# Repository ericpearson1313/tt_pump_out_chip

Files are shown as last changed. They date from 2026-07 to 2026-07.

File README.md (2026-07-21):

   

# Tiny Tapeout Project: Liquid Pump Controller

- [chip datasheet](docs/LPC_Datasheet.pdf)
- [documentation for Tiny Tapeout chip](docs/info.md)
- [documentation for Tiny Tapeout tests](test/README.md)
- [documentation for MAX10 development fpga](max10/fpga.md)
- [documentation for forge production fpga](max10/fpga.md)
- [documentation for the Dev board PCB](pcb/pcb.md)

## What is Tiny Tapeout?

Tiny Tapeout is an educational project that aims to make it easier and cheaper than ever to get your digital and analog designs manufactured on a real chip.

To learn more and get started, visit https://tinytapeout.com.

## Set up your Verilog project

1. Add your Verilog files to the `src` folder.
2. Edit the [info.yaml](info.yaml) and update information about your project, paying special attention to the `source_files` and `top_module` properties. If you are upgrading an existing Tiny Tapeout project, check out our [online info.yaml migration tool](https://tinytapeout.github.io/tt-yaml-upgrade-tool/).
3. Edit [docs/info.md](docs/info.md) and add a description of your project.
4. Adapt the testbench to your design. See [test/README.md](test/README.md) for more information.

The GitHub action will automatically build the ASIC files using [LibreLane](https://www.zerotoasiccourse.com/terminology/librelane/).

## Enable GitHub actions to build the results page

- [Enabling GitHub Pages](https://tinytapeout.com/faq/#my-github-action-is-failing-on-the-pages-part)

## Resources

- [FAQ](https://tinytapeout.com/faq/)
- [Digital design lessons](https://tinytapeout.com/digital_design/)
- [Learn how semiconductors work](https://tinytapeout.com/siliwiz/)
- [Join the community](https://tinytapeout.com/discord)
- [Build your design locally](https://www.tinytapeout.com/guides/local-hardening/)

## What next?

- [Submit your design to the next shuttle](https://app.tinytapeout.com/).
- Edit [this README](README.md) and explain your design, how it works, and how to test it.
- Share your project on your social network of choice:
  - LinkedIn [#tinytapeout](https://www.linkedin.com/search/results/content/?keywords=%23tinytapeout) [@TinyTapeout](https://www.linkedin.com/company/100708654/)
  - Mastodon [#tinytapeout](https://chaos.social/tags/tinytapeout) [@matthewvenn](https://chaos.social/@matthewvenn)
  - X (formerly Twitter) [#tinytapeout](https://twitter.com/hashtag/tinytapeout) [@tinytapeout](https://twitter.com/tinytapeout)
  - Bluesky [@tinytapeout.com](https://bsky.app/profile/tinytapeout.com)

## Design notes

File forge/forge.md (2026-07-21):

### Forge 1K

Excellent tiny cheap one-time-prgrammable 1K lut device perfect for production of a tiny tapeout scale product until ASIC volumes are reached.

The 3mm x 3mm package is tiny, yet can be soldered by hand.

Its not for the faint of heart though, there is no spare I/O and the gate count is tight. I've found it took a full infrastructure of emulators and monitors to confidently and sucessfully put one of these devices in a system. Really the same level that I would use to bring up a chip.

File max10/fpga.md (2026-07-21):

#### FPGA use

FPGA are used for full system simulation, emulation for board bringup
, monitoring a running system, and testing chips. 
As well fpgas are a viable production vehicle until asic voluems are reached.

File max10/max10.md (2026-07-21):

### Intel/Altera MAX10 

a favourite low cost but capable development fpga. For about $20 gets me a 10M04 with 4K Luts with most-excellent free tools. I chose the 144QFP as I can hand solder it, and there is a high density device (for larger builds) the 10M25 which gives me alot of room.

I use the max10 during development in four roles: System Simulation, Emulation, Monitoring, and its used in production for chip Testing.

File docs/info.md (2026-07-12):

<!---

This file is used to generate your project datasheet. Please fill in the information below and delete any unused
sections.

You can also include images in this folder and reference them in the markdown. Each image must be less than
512 kb in size, and the combined size of all images must be less than 1 MB.
-->

## How it works

Function: upon power up, and every 24hrs, chip turns on the pump, and using a current transformer (CT) measures the 6 Hz RMS current and observe a current drop indicating the tank has been emptied, or until a timeout has occured and then turn off the pump. Leds indicate status, and button allows starting a pump out operation at any time.

I like to start with a new chip design with a vision, in the form of a technical datasheet.

datasheet page: [Preliminary Datasheet](LPC_Datasheet.pdf)

## How to test

tests are run with 

    make -B

## External hardware

The chip is the control center for the pumpout controller. It connects to:

    - a 2ch ADC with inputs from : ch0: Current Transformer (CT) and ch1: potentiometer
    - 3 output to LEDs
    - 3 inputs from configureation DIP switch
    - 1 input from a push button
    - 1 output to drive a NPN transistor which will engage a relay to power the pump.

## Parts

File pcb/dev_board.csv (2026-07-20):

Reference | Value | Footprint | Datasheet | DPN | Qty
C1, C2, C4, C9, C10 | 1u | Capacitor_SMD:C_0603_1608Metric | ~ | 399-C0603C105K3RAC7867CT-ND | 5
C3, C5, C6 | 22n | Capacitor_SMD:C_0603_1608Metric | ~ | 445-5663-1-ND | 3
C8 | 4.7u | Capacitor_SMD:C_1206_3216Metric | ~ | 399-C1206C475K5PAC7800CT-ND | 1
C11 | 0.1u | Capacitor_SMD:C_0603_1608Metric | ~ | 399-C0603C104K3RAC7867CT-ND | 1
C12 | 10u | Capacitor_SMD:C_1206_3216Metric | ~ | 399-C1206C106K4PAC7800CT-ND | 1
D1 | RUN | LED_SMD:LED_0603_1608Metric | https://www.digikey.ca/en/products/detail/kingbright/APTD1608LSYCK/7043071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 | 754-2039-1-ND | 1
D2 | FLT | LED_SMD:LED_0603_1608Metric | https://www.digikey.ca/en/products/detail/kingbright/APTD1608LSYCK/7043071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 | 754-2039-1-ND | 1
D3 | TME | LED_SMD:LED_0603_1608Metric | https://www.digikey.ca/en/products/detail/kingbright/APTD1608LSYCK/7043071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 | 754-2039-1-ND | 1
D6 | DT1042-04SO-7 | Package_TO_SOT_SMD:SOT-23-6 | https://www.digikey.ca/en/products/detail/diodes-incorporated/DT1042-04SO-7/4457877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 | DT1042-04SO-7DICT-ND | 1
J1, J2 | Conn_02x13_Odd_Even | Connector_PinSocket_2.54mm:PinSocket_2x13_P2.54mm_Vertical | https://www.digikey.ca/en/products/detail/samtec-inc/ESW-113-12-T-D/7207386 | ESW-113-12-T-D-ND | 2
J4 | Conn_01x05 | Connector_JST:CONN_B5B-ZR-SM4-TF_JST | https://www.digikey.ca/en/products/detail/jst-sales-america-inc/B5B-ZR-SM4-TF/926591 | 455-1684-1-ND | 1
R1 | 0R | Resistor_SMD:R_0603_1608Metric |  | P0.0GCT-ND | 1
R2-R4, R6, R7 | 1K | Resistor_SMD:R_0603_1608Metric |  | 541-1.00KHCT-ND | 5
R5 | DNI | Resistor_SMD:R_0603_1608Metric |  | ~ | 1
R8, R11-R14, R16 | 47 | Resistor_SMD:R_0603_1608Metric |  | 541-47.0HCT-ND | 6
R9 | 3k3 | Resistor_SMD:R_0603_1608Metric |  | 311-3.30KHRCT-ND | 1
R10 | 1K | Potentiometer_SMD:Potentiometer_Bourns_3224J_Horizontal | https://www.digikey.ca/en/products/detail/nidec-components/SM-42TW102/1632327 | SM-42TW102CT-ND | 1
SW1 | SW_DIP_x03 | Button_Switch_SMD:SW_DIP_SPSTx03_Slide_6.7x9.18mm_W6.73mm_P2.54mm_LowProfile_JPin |  | 563-CFS-0300TACT-ND | 1
SW2 | Start | myspace pcb:SW_SPST_HP03 | https://www.digikey.ca/en/products/detail/nkk-switches/HP0315AFKP2-R/1242035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 | 360-2595-1-ND | 1
TP1 | GND | TestPoint:TestPoint_Keystone_5000-5004_Miniature | https://www.digikey.ca/en/products/detail/keystone-electronics/1037/315153 | 36-1037-ND | 1
U1 | XS-LPC-01 | myspace pcb:QFN-24-3x3mm | https://github.com/ericpearson1313/tt_pump_out_chip | ~ | 1
U2 | MCP3202 | Package_SO:MSOP-8_3x3mm_P0.65mm | https://ww1.microchip.com/downloads/aemDocuments/documents/APID/ProductDocuments/DataSheets/21034F.pdf | MCP3202-CI/MS-ND | 1
U3 | NCP114ASN280T1G | Package_TO_SOT_SMD:SOT-23-5 | https://www.digikey.ca/en/products/detail/onsemi/NCP114ASN280T1G/6560603 | NCP114ASN280T1GOSCT-ND | 1
U6 | TLV74311 | Package_TO_SOT_SMD:SOT-23-5 | https://www.digikey.ca/en/products/detail/texas-instruments/TLV74311PDBVR/7593919 | 296-50002-1-ND | 1

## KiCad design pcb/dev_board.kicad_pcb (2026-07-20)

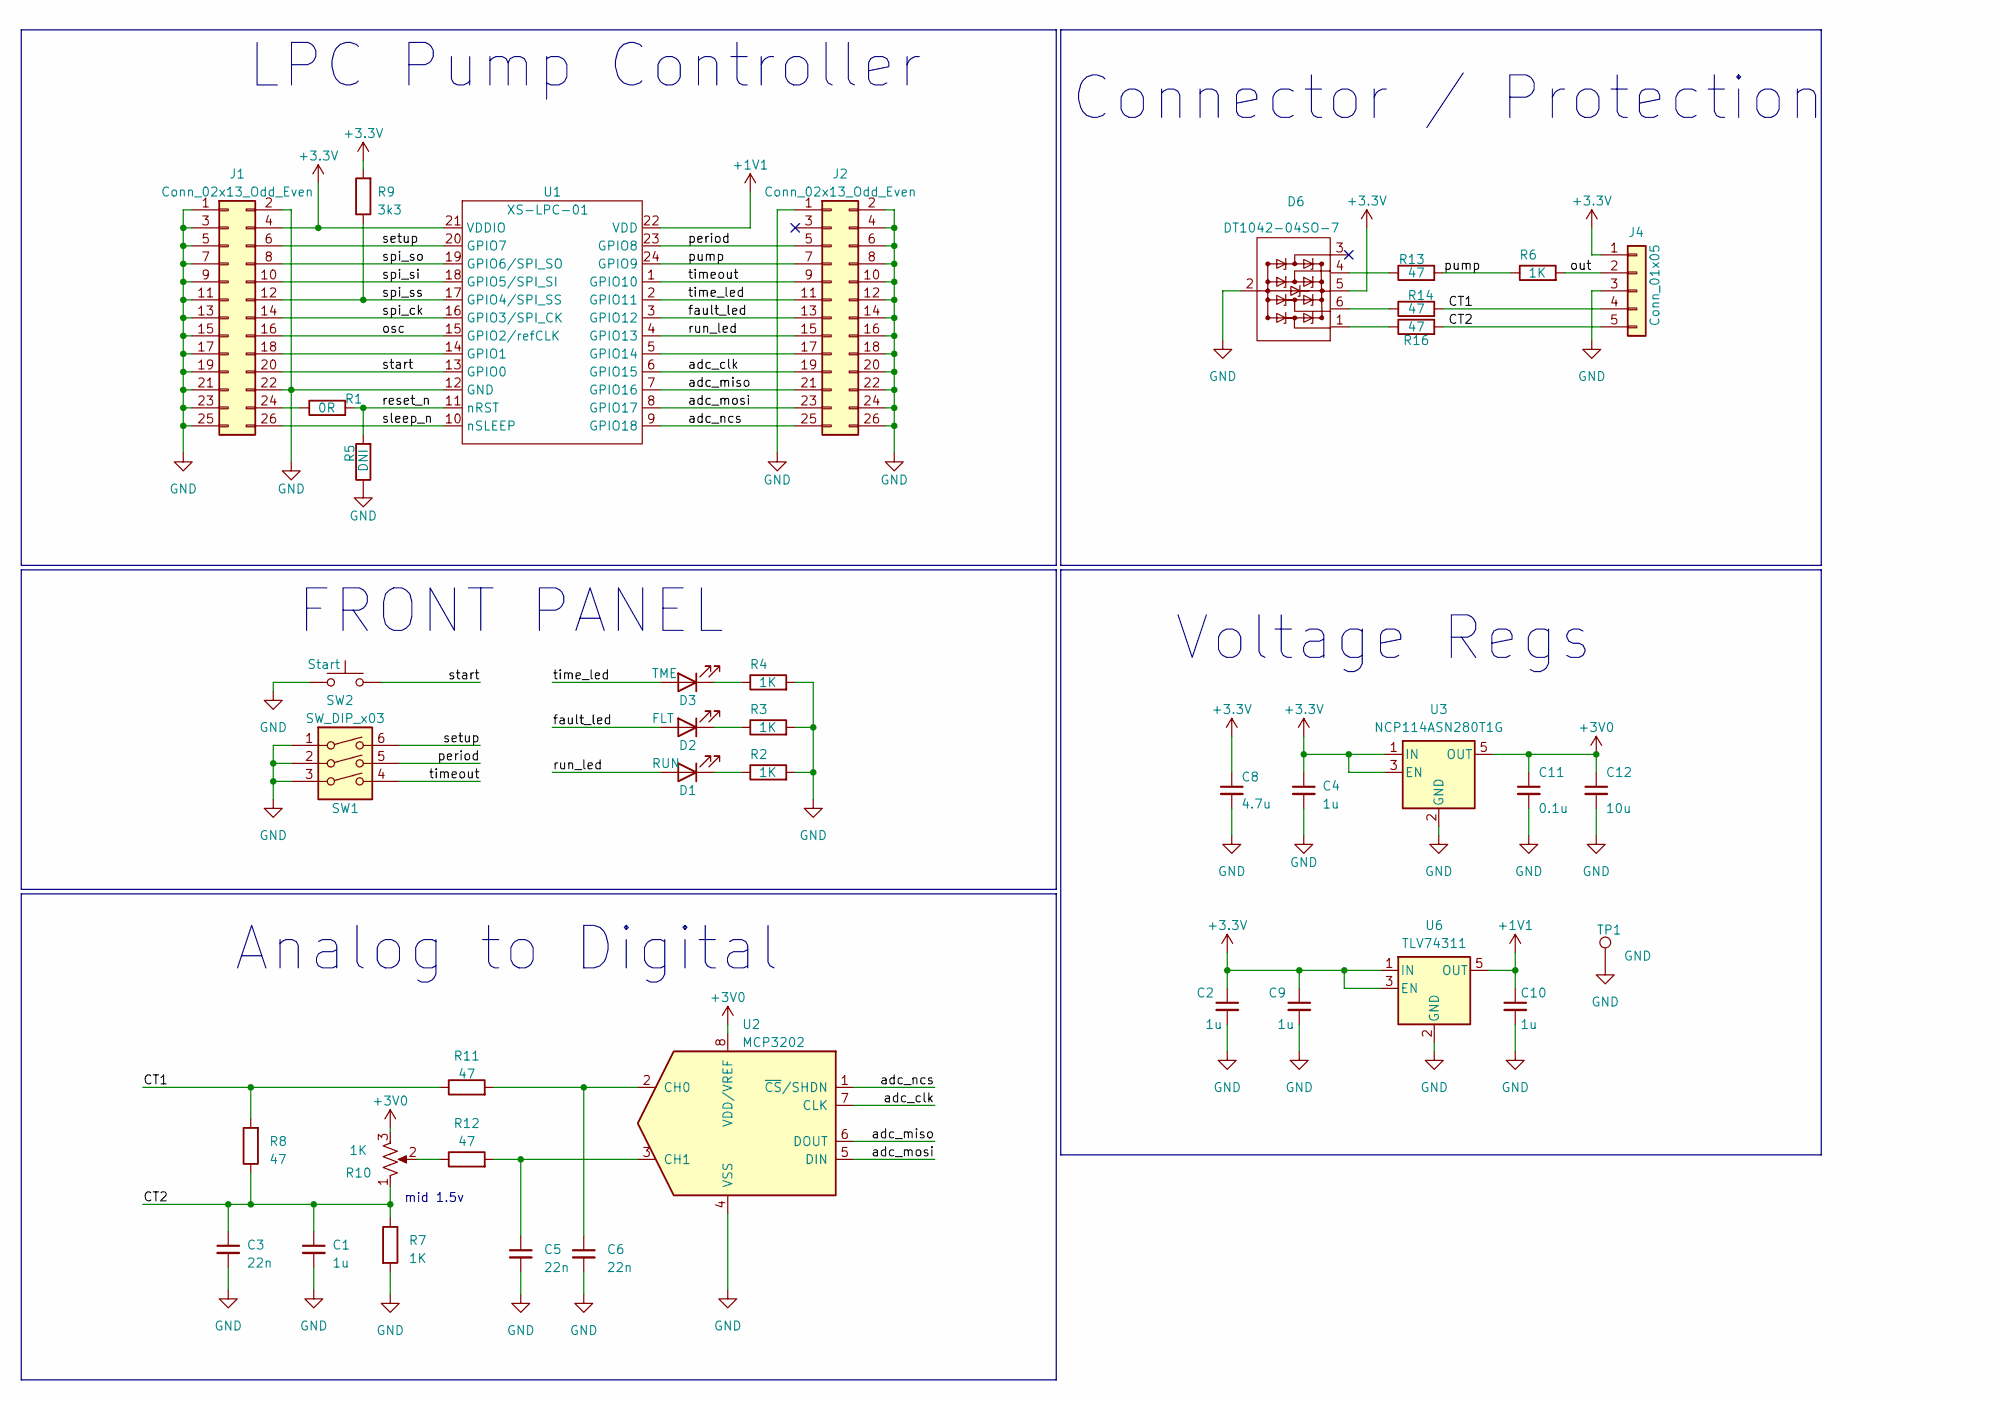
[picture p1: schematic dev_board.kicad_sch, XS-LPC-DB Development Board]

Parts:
C1, C2, C4, C9, C10: 1u; C_0603_1608Metric
C3, C5, C6: 22n; C_0603_1608Metric
C8: 4.7u; C_1206_3216Metric
C11: 0.1u; C_0603_1608Metric
C12: 10u; C_1206_3216Metric
D1: RUN; LED_0603_1608Metric
D2: FLT; LED_0603_1608Metric
D3: TME; LED_0603_1608Metric
D6: DT1042-04SO-7; SOT-23-6
J1, J2: Conn_02x13_Odd_Even; PinSocket_2x13_P2.54mm_Vertical
J4: Conn_01x05; CONN_B5B-ZR-SM4-TF_JST
R1: 0R; R_0603_1608Metric; JLC C491211
R2, R3, R4, R6, R7: 1K; R_0603_1608Metric; JLC C319967
R5: DNI; R_0603_1608Metric; JLC C491211
R8, R11, R12, R13, R14, R16: 47; R_0603_1608Metric; JLC C319967
R9: 3k3; R_0603_1608Metric; JLC C319967
R10: 1K; Potentiometer_Bourns_3224J_Horizontal
SW1: SW_DIP_x03; SW_DIP_SPSTx03_Slide_6.7x9.18mm_W6.73mm_P2.54mm_LowProfile_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
SW2: Start; SW_SPST_HP03
TP1: GND; TestPoint_Keystone_5000-5004_Miniature
U1: XS-LPC-01; QFN-24-3x3mm
U2: MCP3202; MSOP-8_3x3mm_P0.65mm
U3: NCP114ASN280T1G; SOT-23-5
U6: TLV74311; SOT-23-5

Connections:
+1V1: C10.1, U1.22 (VDD), U6.5 (OUT)
+3.3V: C2.1, C4.1, C8.1, C9.1, D6.5 (vdd), J1.4, J4.1, R9.2, U1.21 (VDDIO), U3.1 (IN), U3.3 (EN), U6.1 (IN), U6.3 (EN)
+3V0: C11.1, C12.1, R10.3, U2.8 (VDD/VREF), U3.5 (OUT)
/CT1: J4.4, R8.2, R11.1, R14.2
/CT2: C1.1, C3.1, J4.5, R7.1, R8.1, R10.1, R16.2
/adc_clk: J2.19, U1.6 (GPIO15), U2.7 (CLK)
/adc_miso: J2.21, U1.7 (GPIO16), U2.6 (DOUT)
/adc_mosi: J2.23, U1.8 (GPIO17), U2.5 (DIN)
/adc_ncs: J2.25, U1.9 (GPIO18), U2.1 (~CS/SHDN)
/fault_led: D2.2 (A), J2.13, U1.3 (GPIO12)
/osc: J1.16, U1.15 (GPIO2/refCLK)
/out: J4.2, R6.2
/period: J2.5, SW1.5, U1.23 (GPIO8)
/pump: J2.7, R6.1, R13.2, U1.24 (GPIO9)
/reset_n: R1.2, R5.2, U1.11 (nRST)
/run_led: D1.2 (A), J2.15, U1.4 (GPIO13)
/setup: J1.6, SW1.6, U1.20 (GPIO7)
/sleep_n: J1.26, U1.10 (nSLEEP)
/spi_ck: J1.14, U1.16 (GPIO3/SPI_CK)
/spi_si: J1.10, U1.18 (GPIO5/SPI_SI)
/spi_so: J1.8, U1.19 (GPIO6/SPI_SO)
/spi_ss: J1.12, R9.1, U1.17 (GPIO4/SPI_SS)
/start: J1.20, SW2.2, U1.13 (GPIO0)
/time_led: D3.2 (A), J2.11, U1.2 (GPIO11)
/timeout: J2.9, SW1.4, U1.1 (GPIO10)
GND: C1.2, C2.2, C3.2, C4.2, C5.2, C6.2, C8.2, C9.2, C10.2, C11.2, C12.2, D6.2 (vss), J1.1, J1.2, J1.3, J1.5, J1.7, J1.9, J1.11, J1.13, J1.15, J1.17, J1.19, J1.21, J1.22, J1.23, J1.25, J2.1, J2.2, J2.4, J2.6, J2.8, J2.10, J2.12, J2.14, J2.16, J2.18, J2.20, J2.22, J2.24, J2.26, J4.3, R2.2, R3.2, R4.2, R5.1, R7.2, SW1.1, SW1.2, SW1.3, SW2.1, TP1.1, U1.12 (GND), U2.4 (VSS), U3.2 (GND), U6.2 (GND)
unnamed: D1.1 (K), R2.1
unnamed: D2.1 (K), R3.1
unnamed: D3.1 (K), R4.1
unnamed: D6.4 (K1), R13.1
unnamed: D6.6 (K2), R14.1
unnamed: D6.1 (X1), R16.1
unnamed: J1.18, U1.14 (GPIO1)
unnamed: J1.24, R1.1
unnamed: J2.17, U1.5 (GPIO14)
unnamed: R10.2, R12.1
unnamed: C6.1, R11.2, U2.2 (CH0)
unnamed: C5.1, R12.2, U2.3 (CH1)

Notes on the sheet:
LPC Pump Controller
Voltage Regs
FRONT PANEL
Connector / Protection
Analog to Digital
mid 1.5v

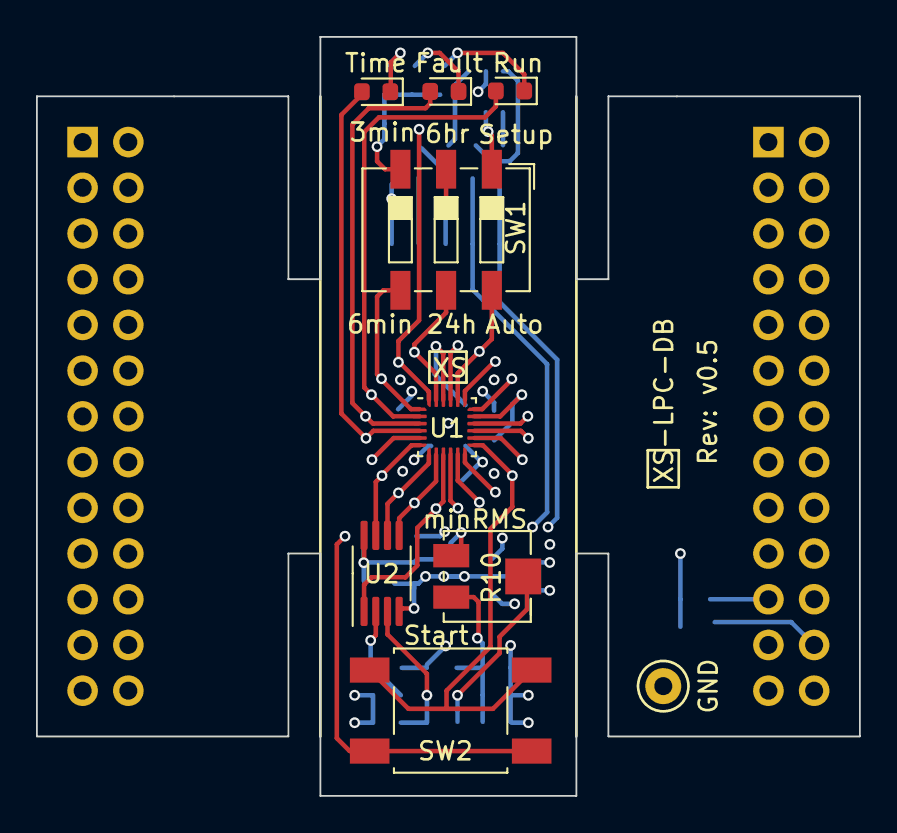
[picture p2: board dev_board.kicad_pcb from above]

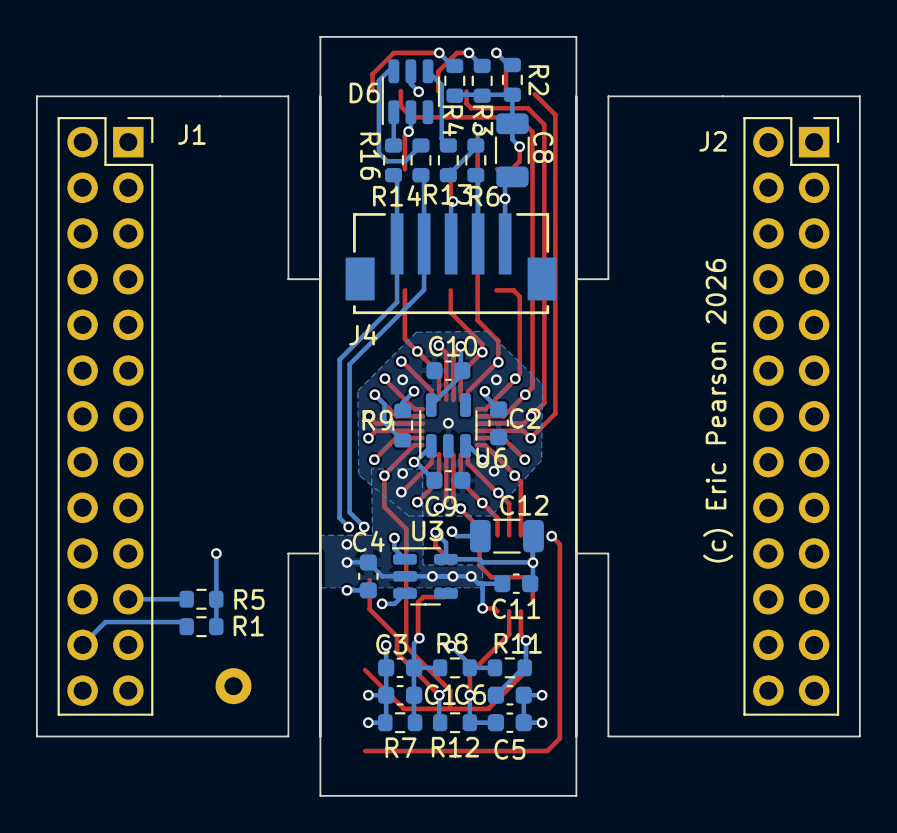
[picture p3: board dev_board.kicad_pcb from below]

Board: 6 copper layers, 45.7 x 42.2 mm, 40 parts (31 on the bottom side), 38 nets.

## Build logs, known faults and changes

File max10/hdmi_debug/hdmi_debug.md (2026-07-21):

### HDMI debug

I feel all fpga project should have an HDMI connector dirctly wired to the fpga. It uses 4 differential signals, but gives unprecidented visibily into the device, that persists. At any time in the future hook up an HDMI montitor to the chip and you can see the debug screen (created during design debug). No software, not setup, no nothing, just an HDMI cable and monitor.

Creating the HDMI output sync, encoding etc is tiny. Adding a 32Mbyte psram SPI8 interface allows recording data, and basic logic allows pan zoom of the data.

I typicallyi set this up as 3Mhz recording for 1.3sec of 5 analog and 8 digital signals.

Live test overlays are used to display the digital values of critidal signals. 

Multiple 'scopes' have been built including slow scroll trasient captuting flwo, as well as the high res signals at full detail.

always, always, always. Except if you don't have space or IO :)

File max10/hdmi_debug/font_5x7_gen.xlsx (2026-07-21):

8'h41,8'h42,8'h43,8'h44,8'h45,8'h46,8'h47,8'h48,8'h49,8'h4A, | A |  |  |  |  | 8'h41, | B |  |  |  |  | 8'h42, | C |  |  |  |  | 8'h43, | D |  |  |  |  | 8'h44, | E |  |  |  |  | 8'h45, | F |  |  |  |  | 8'h46, | G |  |  |  |  | 8'h47, | H |  |  |  |  | 8'h48, | I |  |  |  |  | 8'h49, | J
01110_11110_01110_11110_11111_11111_01110_10001_01110_00001_ |  | 1 | 1 | 1 |  | 01110_ | 1 | 1 | 1 | 1 |  | 11110_ |  | 1 | 1 | 1 |  | 01110_ | 1 | 1 | 1 | 1 |  | 11110_ | 1 | 1 | 1 | 1 | 1 | 11111_ | 1 | 1 | 1 | 1 | 1 | 11111_ |  | 1 | 1 | 1 |  | 01110_ | 1 |  |  |  | 1 | 10001_ |  | 1 | 1 | 1 |  | 01110_
10001_10001_10001_10001_10000_10000_10001_10001_00100_00001_ | 1 |  |  |  | 1 | 10001_ | 1 |  |  |  | 1 | 10001_ | 1 |  |  |  | 1 | 10001_ | 1 |  |  |  | 1 | 10001_ | 1 |  |  |  |  | 10000_ | 1 |  |  |  |  | 10000_ | 1 |  |  |  | 1 | 10001_ | 1 |  |  |  | 1 | 10001_ |  |  | 1 |  |  | 00100_
10001_10001_10000_10001_10000_10000_10000_10001_00100_00001_ | 1 |  |  |  | 1 | 10001_ | 1 |  |  |  | 1 | 10001_ | 1 |  |  |  |  | 10000_ | 1 |  |  |  | 1 | 10001_ | 1 |  |  |  |  | 10000_ | 1 |  |  |  |  | 10000_ | 1 |  |  |  |  | 10000_ | 1 |  |  |  | 1 | 10001_ |  |  | 1 |  |  | 00100_
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

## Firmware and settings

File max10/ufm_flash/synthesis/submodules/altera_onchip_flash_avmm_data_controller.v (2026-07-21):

// (C) 2001-2024 Intel Corporation. All rights reserved.
// Your use of Intel Corporation's design tools, logic functions and other 
// software and tools, and its AMPP partner logic functions, and any output 
// files from any of the foregoing (including device programming or simulation 
// files), and any associated documentation or information are expressly subject 
// to the terms and conditions of the Intel Program License Subscription 
// Agreement, Intel FPGA IP License Agreement, or other applicable 
// license agreement, including, without limitation, that your use is for the 
// sole purpose of programming logic devices manufactured by Intel and sold by 
// Intel or its authorized distributors.  Please refer to the applicable 
// agreement for further details.


////////////////////////////////////////////////////////////////////
//
//  ALTERA_ONCHIP_FLASH_AVMM_DATA_CONTROLLER (SERIAL-to-SERIAL MODE)
//
//  Copyright (C) 1991-2013 Altera Corporation
//  Your use of Altera Corporation's design tools, logic functions 
//  and other software and tools, and its AMPP partner logic 
//  functions, and any output files from any of the foregoing 
//  (including device programming or simulation files), and any 
//  associated documentation or information are expressly subject 
//  to the terms and conditions of the Altera Program License 
//  Subscription Agreement, Altera MegaCore Function License 
//  Agreement, or other applicable license agreement, including, 
//  without limitation, that your use is for the sole purpose of 
//  programming logic devices manufactured by Altera and sold by 
//  Altera or its authorized distributors.  Please refer to the 
//  applicable agreement for further details.
//
////////////////////////////////////////////////////////////////////

// synthesis VERILOG_INPUT_VERSION VERILOG_2001

`timescale 1 ps / 1 ps

module altera_onchip_flash_avmm_data_controller (
    // To/From System
    clock,
    reset_n,
    
    // To/From Flash IP interface
    flash_busy,
    flash_se_pass,
    flash_sp_pass,
    flash_osc,
    flash_drdout,
    flash_xe_ye,
    flash_se,
    flash_arclk,
    flash_arshft,
    flash_drclk,
    flash_drshft,
    flash_drdin,
    flash_nprogram,
    flash_nerase,
    flash_ardin,
        
    // To/From Avalon_MM data slave interface
    avmm_read,
    avmm_write,
    avmm_addr,
    avmm_writedata,
    avmm_burstcount,
    avmm_waitrequest,
    avmm_readdatavalid,
    avmm_readdata,
        
    // To/From Avalon_MM csr slave interface
    csr_control,
    csr_status
);

    parameter READ_AND_WRITE_MODE = 0;
    parameter WRAPPING_BURST_MODE = 0;
    parameter DATA_WIDTH = 32;
    parameter AVMM_DATA_ADDR_WIDTH = 20;
    parameter AVMM_DATA_BURSTCOUNT_WIDTH = 4;
    parameter FLASH_ADDR_WIDTH = 23;
    parameter FLASH_SEQ_READ_DATA_COUNT = 2;    //number of 32-bit data per sequential read
    parameter FLASH_READ_CYCLE_MAX_INDEX = 3;    //period to for each sequential read
    parameter FLASH_ADDR_ALIGNMENT_BITS = 1;     //number of last addr bits for alignment
    parameter FLASH_RESET_CYCLE_MAX_INDEX = 28;    //period that required by flash before back to idle for erase and program operation
    parameter FLASH_BUSY_TIMEOUT_CYCLE_MAX_INDEX = 112; //flash busy timeout period (960ns)
    parameter FLASH_ERASE_TIMEOUT_CYCLE_MAX_INDEX = 40603248; //erase timeout period (350ms)
    parameter FLASH_WRITE_TIMEOUT_CYCLE_MAX_INDEX = 35382; //write timeout period (305us)
    parameter MIN_VALID_ADDR = 1;
    parameter MAX_VALID_ADDR = 1;
    parameter SECTOR1_START_ADDR = 1;
    parameter SECTOR1_END_ADDR = 1;
    parameter SECTOR2_START_ADDR = 1;
    parameter SECTOR2_END_ADDR = 1;
    parameter SECTOR3_START_ADDR = 1;
    parameter SECTOR3_END_ADDR = 1;
    parameter SECTOR4_START_ADDR = 1;
    parameter SECTOR4_END_ADDR = 1;
    parameter SECTOR5_START_ADDR = 1;
    parameter SECTOR5_END_ADDR = 1;
    parameter SECTOR_READ_PROTECTION_MODE = 5'b11111;
    parameter SECTOR1_MAP = 1;
    parameter SECTOR2_MAP = 1;
    parameter SECTOR3_MAP = 1;
    parameter SECTOR4_MAP = 1;
    parameter SECTOR5_MAP = 1;
    parameter ADDR_RANGE1_END_ADDR = 1;
    parameter ADDR_RANGE2_END_ADDR = 1;
    parameter ADDR_RANGE1_OFFSET = 1;
    parameter ADDR_RANGE2_OFFSET = 1;
    parameter ADDR_RANGE3_OFFSET = 1;

    localparam [1:0]    ERASE_ST_IDLE = 0,
                        ERASE_ST_PENDING = 1,
                        ERASE_ST_BUSY = 2;

    localparam [1:0]    STATUS_IDLE = 0,
                        STATUS_BUSY_ERASE = 1,
                        STATUS_BUSY_WRITE = 2,
                        STATUS_BUSY_READ = 3;
    
    // State 0~4 is common for both RW and read only mode. State 5~8 is only needed in RW mode.
    localparam [3:0]    OP_STATE_IDLE = 0,
                        OP_STATE_ADDR = 1,
                        OP_STATE_READ_SHIFT = 2,
                        OP_STATE_READ_DATA = 3,
                        OP_STATE_CLEAR = 4,
                        OP_STATE_WRITE = 5,
                        OP_STATE_WAIT_BUSY = 6,
                        OP_STATE_WAIT_DONE = 7,
                        OP_STATE_RESET = 8;

    // To/From System
    input clock;
    input reset_n;
    
    // To/From Flash IP interface
    input flash_busy;
    input flash_se_pass;
    input flash_sp_pass;
    input flash_osc;
    input [DATA_WIDTH-1:0] flash_drdout;
    output flash_xe_ye;
    output flash_se;
    output flash_arclk;
    output flash_arshft;
    output flash_drclk;
    output flash_drshft;
    output flash_drdin;
    output flash_nprogram;
    output flash_nerase;
    output [FLASH_ADDR_WIDTH-1:0] flash_ardin;
        
    // To/From Avalon_MM data slave interface
    input avmm_read;
    input avmm_write;
    input [AVMM_DATA_ADDR_WIDTH-1:0] avmm_addr;
    input avmm_writedata;
    input [AVMM_DATA_BURSTCOUNT_WIDTH-1:0] avmm_burstcount;
    output avmm_waitrequest;
    output avmm_readdatavalid;
    output avmm_readdata;
        
    // To/From Avalon_MM csr slave interface
    input [31:0] csr_control;
    output [9:0] csr_status;

    reg reset_n_reg1;
    reg reset_n_reg2;
    reg flash_busy_reg;
    reg flash_busy_clear_reg;
    reg flash_addr_neg_reg;
    reg flash_drdin_neg_reg;
    reg flash_drdout_neg_reg;
    reg [AVMM_DATA_BURSTCOUNT_WIDTH-1:0] cur_burstcount;
    reg [1:0] csr_status_busy;
    reg csr_status_e_pass;
    reg csr_status_w_pass;
    reg csr_status_r_pass;

    reg [3:0] op_state;
    reg op_wait;
    reg op_wait_neg_reg;
    reg op_count_start;
    reg [FLASH_ADDR_WIDTH-1:0] op_addr;
    reg op_wrap_back_addr;
    reg op_range2_addr;
    reg op_range3_addr;
    reg op_illegal_write_addr;
    reg op_scan_busy;
    
    reg arclk_en;
    reg enable_arclk_neg_reg;
    reg enable_arclk_neg_pos_reg;
    reg enable_drclk_neg_reg;
    reg enable_drclk_neg_pos_reg;
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

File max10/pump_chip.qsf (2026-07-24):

# -------------------------------------------------------------------------- #
#
# Copyright (C) 2023  Intel Corporation. All rights reserved.
# Your use of Intel Corporation's design tools, logic functions 
# and other software and tools, and any partner logic 
# functions, and any output files from any of the foregoing 
# (including device programming or simulation files), and any 
# associated documentation or information are expressly subject 
# to the terms and conditions of the Intel Program License 
# Subscription Agreement, the Intel Quartus Prime License Agreement,
# the Intel FPGA IP License Agreement, or other applicable license
# agreement, including, without limitation, that your use is for
# the sole purpose of programming logic devices manufactured by
# Intel and sold by Intel or its authorized distributors.  Please
# refer to the applicable agreement for further details, at
# https://fpgasoftware.intel.com/eula.
#
# -------------------------------------------------------------------------- #
#
# Quartus Prime
# Version 23.1std.0 Build 991 11/28/2023 SC Lite Edition
# Date created = 11:07:06  May 16, 2024
#
# -------------------------------------------------------------------------- #
#
# Notes:
#
# 1) The default values for assignments are stored in the file:
#		grid_tie_assignment_defaults.qdf
#    If this file doesn't exist, see file:
#		assignment_defaults.qdf
#
# 2) Intel recommends that you do not modify this file. This
#    file is updated automatically by the Quartus Prime software
#    and any changes you make may be lost or overwritten.
#
# -------------------------------------------------------------------------- #


set_global_assignment -name FAMILY "MAX 10"
set_global_assignment -name DEVICE 10M04SCE144C8G
set_global_assignment -name TOP_LEVEL_ENTITY pump_chip
set_global_assignment -name ORIGINAL_QUARTUS_VERSION 23.1STD.0
set_global_assignment -name PROJECT_CREATION_TIME_DATE "11:07:06  MAY 16, 2024"
set_global_assignment -name LAST_QUARTUS_VERSION "23.1std.1 Lite Edition"
set_global_assignment -name PROJECT_OUTPUT_DIRECTORY output_files
set_global_assignment -name MIN_CORE_JUNCTION_TEMP 0
set_global_assignment -name MAX_CORE_JUNCTION_TEMP 85
set_global_assignment -name DEVICE_FILTER_PACKAGE EQFP
set_global_assignment -name DEVICE_FILTER_PIN_COUNT 144
set_global_assignment -name DEVICE_FILTER_SPEED_GRADE 8
set_global_assignment -name ERROR_CHECK_FREQUENCY_DIVISOR 256
set_global_assignment -name EDA_SIMULATION_TOOL "Questa Intel FPGA (Verilog)"
set_global_assignment -name EDA_TIME_SCALE "1 ps" -section_id eda_simulation
set_global_assignment -name EDA_OUTPUT_DATA_FORMAT "VERILOG HDL" -section_id eda_simulation
set_global_assignment -name EDA_GENERATE_FUNCTIONAL_NETLIST OFF -section_id eda_board_design_timing
set_global_assignment -name EDA_GENERATE_FUNCTIONAL_NETLIST OFF -section_id eda_board_design_symbol
set_global_assignment -name EDA_GENERATE_FUNCTIONAL_NETLIST OFF -section_id eda_board_design_signal_integrity
set_global_assignment -name EDA_GENERATE_FUNCTIONAL_NETLIST OFF -section_id eda_board_design_boundary_scan
set_global_assignment -name POWER_PRESET_COOLING_SOLUTION "23 MM HEAT SINK WITH 200 LFPM AIRFLOW"
set_global_assignment -name POWER_BOARD_THERMAL_MODEL "NONE (CONSERVATIVE)"
set_global_assignment -name EDA_TEST_BENCH_ENABLE_STATUS TEST_BENCH_MODE -section_id eda_simulation
set_global_assignment -name EDA_NATIVELINK_SIMULATION_TEST_BENCH testbench -section_id eda_simulation
set_global_assignment -name EDA_TEST_BENCH_NAME testbench -section_id eda_simulation
set_global_assignment -name EDA_DESIGN_INSTANCE_NAME NA -section_id testbench
set_global_assignment -name EDA_TEST_BENCH_MODULE_NAME testbench -section_id testbench
set_global_assignment -name EDA_TEST_BENCH_FILE testbench.sv -section_id testbench
set_global_assignment -name FLOW_ENABLE_POWER_ANALYZER ON
set_global_assignment -name POWER_DEFAULT_INPUT_IO_TOGGLE_RATE "12.5 %"
set_location_assignment PIN_33 -to clk_out
set_location_assignment PIN_27 -to clk_in
set_location_assignment PIN_28 -to reset_n
set_location_assignment PIN_86 -to spi8_data_pad[7]
set_location_assignment PIN_84 -to spi8_data_pad[6]
set_location_assignment PIN_79 -to spi8_data_pad[5]
set_location_assignment PIN_76 -to spi8_data_pad[4]
set_location_assignment PIN_77 -to spi8_data_pad[3]
set_location_assignment PIN_75 -to spi8_data_pad[2]
set_location_assignment PIN_85 -to spi8_data_pad[1]
set_location_assignment PIN_78 -to spi8_data_pad[0]
set_location_assignment PIN_74 -to spi_ds
set_location_assignment PIN_81 -to spi_ncs
set_location_assignment PIN_87 -to spi_clk0
set_location_assignment PIN_13 -to anain[7]
set_location_assignment PIN_12 -to anain[6]
set_location_assignment PIN_11 -to anain[5]
set_location_assignment PIN_10 -to anain[4]
set_location_assignment PIN_8 -to anain[3]
set_location_assignment PIN_7 -to anain[2]
set_location_assignment PIN_6 -to anain[1]
set_location_assignment PIN_110 -to digio[6]
set_location_assignment PIN_112 -to digio[5]
set_location_assignment PIN_111 -to digio[4]
set_location_assignment PIN_114 -to digio[3]
set_location_assignment PIN_113 -to digio[2]
set_location_assignment PIN_119 -to digio[1]
set_location_assignment PIN_14 -to anain[8]
set_location_assignment PIN_118 -to digio[0]
set_location_assignment PIN_52 -to hdmi2_ck
set_location_assignment PIN_50 -to "hdmi2_ck(n)"
set_location_assignment PIN_56 -to hdmi2_d0
set_location_assignment PIN_55 -to "hdmi2_d0(n)"
set_location_assignment PIN_58 -to hdmi2_d1
set_location_assignment PIN_57 -to "hdmi2_d1(n)"
set_location_assignment PIN_60 -to hdmi2_d2
set_location_assignment PIN_59 -to "hdmi2_d2(n)"
set_location_assignment PIN_80 -to spi_nrst
set_global_assignment -name ENABLE_OCT_DONE OFF
set_global_assignment -name ENABLE_BOOT_SEL_PIN OFF
set_global_assignment -name USE_CONFIGURATION_DEVICE ON
set_global_assignment -name ENABLE_CRC_ERROR_PIN ON
set_global_assignment -name CRC_ERROR_OPEN_DRAIN OFF
set_global_assignment -name OUTPUT_IO_TIMING_NEAR_END_VMEAS "HALF VCCIO" -rise
set_global_assignment -name OUTPUT_IO_TIMING_NEAR_END_VMEAS "HALF VCCIO" -fall
set_global_assignment -name OUTPUT_IO_TIMING_FAR_END_VMEAS "HALF SIGNAL SWING" -rise
set_global_assignment -name OUTPUT_IO_TIMING_FAR_END_VMEAS "HALF SIGNAL SWING" -fall
set_instance_assignment -name IO_STANDARD "3.3-V LVTTL" -to anain[1]
set_instance_assignment -name IO_STANDARD "3.3-V LVTTL" -to anain[2]
set_instance_assignment -name IO_STANDARD "3.3-V LVTTL" -to anain[3]
set_instance_assignment -name IO_STANDARD "3.3-V LVTTL" -to anain[4]
set_instance_assignment -name IO_STANDARD "3.3-V LVTTL" -to anain[5]
set_instance_assignment -name IO_STANDARD "3.3-V LVTTL" -to anain[6]
set_instance_assignment -name IO_STANDARD "3.3-V LVTTL" -to anain[7]
set_instance_assignment -name IO_STANDARD "3.3-V LVTTL" -to anain[8]
set_instance_assignment -name IO_STANDARD "3.3-V LVTTL" -to clk_in
set_instance_assignment -name IO_STANDARD LVDS_E_3R -to clk_out
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

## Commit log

2026-07-10 LPC chip datasheet page, Dev board PCB floorplan, UX, DIN Module 3 screw terminal sytem integration. Nice
    [dev_board.kicad_pcb, dev_board.kicad_sch]
2026-07-12 test action flow for TT
    Added detailed explanation of pump operation and testing instructions.
2026-07-18 V0.2 schem, bom, pcb. Ready to route
    [dev_board.csv, dev_board.kicad_pcb, dev_board.kicad_sch]
2026-07-20 PCB Tapeout v0.5 LPC_DB development board, schematic, bom, datasheets updated.
    [dev_board.csv, dev_board.kicad_pcb, dev_board.kicad_sch]
2026-07-21 Added MAX 10 emulator foundation, connected pump IO, wrapped TT chip (pump_core.sv), and runnign with HDMI video pan/zoom running.
    [font_5x7_gen.xlsx]
2026-07-21 Added v0.5 GERBERS for development board (DB) pcb O7-20 tapeout.
2026-07-21 Update links in README for test and PCB documentation
2026-07-22 ADC interfaces and integration of cordic and adc
2026-07-22 add ADC master logic, tiny, serial out
2026-07-22 Added the asyn adc monitor interface module type 2/3
2026-07-22 Added the simulated device spi slave, now we have all 3
2026-07-23 ADC If's integrated, verilator running, debug in process
2026-07-23 ADC sub system integrated and running chip level sims
2026-07-24 Disconnected the adc I/O for fpga simualtion accelleration (internal adc master, adc simulatin, and monitor). Reconnect later
2026-07-24 MAX10 Fpga builds with Integrated lpc_core adc master/sim/monitor cordic
